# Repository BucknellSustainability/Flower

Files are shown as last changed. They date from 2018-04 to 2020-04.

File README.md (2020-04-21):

# Overview
Flower is a data collection and visualization system made for the Renewable Energy Scholars at Bucknell University. It is made of several components that require each other to function. The purpose of the project is to make research easier as well as publicize the sustainability efforts at Bucknell.

# How to use this project
There are `README.md`s in each of the main directories for how to use each component of the project. You will need a MySQL DB running (`/backend/sql`), run the Flask server (`/backend`), compile the React code and run the php server (`/web`), and put code on the Raspberry Pis (`/raspberrypi`), and load programs onto Arduinos (`/arduino`).  

# Running system at Bucknell
We suggest running this system with Bucknell linuxremote servers because that is what we developed on. Any other system is not guarenteed to work, but we will have instructions to give it a shot.

If attempting to run on Bucknell systems, we advise cloning the repo into a user's `~/public_html/` directory (create it if it doesn't exist) to enable the Bucknell Apache server to handle the web page serving.

The system needs to be run on linuxremote3 for the below part to function.

Now go into the script directory and run:
```
./restart_flask.sh
```
If any changes need to be done to the flask server, just run that script again to restart it

# API Keys and Deployment Specific Values
API Keys and other deployment specific values have been removed from the repo to ensure security and flexibility for different deployments.  You will NEED to complete steps 1-6 to have any component of the project to work.

1. Create a file called `config.json` in the repo's root directory.
2. Add this code:
```
{
  "DB_URL" : "",
  "DB_USERNAME" : "",
  "DB_PASSWORD" : "",
  "DB_NAME": ""
}
```
3. Fill out all values of the empty strings with information for your DB/API key info
4. Create a file called `deployment.json` in the repo's root directory.  There are all things unique to your deployment.
5. Add this code:
```
{
 "APPROVAL_LINK": "",
  "FLASK_SERVER": "",
  "GOOGLE_CLIENT_ID": "",
  "REDIRECT_URL": "" 
}
```
6. Fill out all values of the empty string with the information for your deployment
7. Access the values where needed:
    * Python:
       ```
       import json
       with open('path/to/config.json', 'r') as f:
           config = json.load(f)

       config['KEY_NAME']
       ```
    * PHP:
      ```
      $config = json_decode(file_get_contents("path/to/config.json"));
      printf("%s", $config->KEY_NAME);
      ```
    * JS:
      !!!This should only be used with the deployment.json so that DB credentials or other important information isn't leaked on the client side with `config.json`
      ```
      <script src="https://ajax.googleapis.com/ajax/libs/jquery/3.3.1/jquery.min.js"></script> 
      <script type="text/javascript" src="../common/load-deployment.js" ></script>
      ...
      deploy_config["KEY_NAME"]
      ```
`KEY_NAME` is the key string in your config file such as `DB_NAME` or `FLASK_SERVER`.

This `config.json` and `deployment.json` won't get committed because it is in the `.gitignore` so you will need to do this for each clone of the repo, but it should persist unless you delete the file.

## Linters

### Python - autopep8
To install autopep8 run
```
pip install autopep8
```
Install the `python-autopep8` package in Atom with either `apm install python-autopep8` or through the built in Atom package manager.

Then to run the linter in Atom, highlight all of the text you want to format and then press `Ctrl-shift-p` and type in `autopep8` and then press `Enter` to format the Python code.

You can also run it from the command line with `autopep8 [--in-place] [other-options] filename`.

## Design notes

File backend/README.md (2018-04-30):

# Setup on any system
Coming soon to a movie theatre near you

# Manual setting up backend on Bucknell's linuxremote
1. Make sure that you have a `config.json` and `deployment.json` file in the root directory of the repo. If you don't, read instructions in `/README.md`

2. Run the folowing commands to make sure you are using python 3.6
```
module load python/3.6
```

3. Run the following commands to install all necessary python packages
```
pip install --user --upgrade google-auth flask flask-mysql
```

4. Go to the `scripts` directory and run the flask starting script
```
./restart_flask.sh
```

# Using the api
Each of these end points need to be accessed by an http request to `https://eg.bucknell.edu/energyhill/{endpoint}` where `{endpoint}` which is described below.  Each http request needs to be accompanied with parameters described below.

Generally, hardcoding the URL shouldn't be in code, but instead you should use the deployment config setup (information found in `/README.md`)

## Reading from the DB
- `{endpoint}`: `read`
- allowed http requests: `GET`
- parameters:
    - `table`: the table which to pull data from. Must be a valid table in the DB.
    - `fields`: the column names which should be retrieved. Must be valid column of `table`
    - `condition_fields`: the condition field to compare a value equal to.  Must be a valid column name for `table` or `null` (if `null`, then values must also be `null`)
    - `condition_values`: the values that must match up with the `condition_fields` to make a condition. Each subsequent field/value pair will be `AND`ed with the others.
- form: `SELECT fields FROM table WHERE condition_fields[0] = condition_values[0] AND condition_fields[1] = condition_value[1] AND ...`
- returns: JSON serialization of DB output

## Inserting into the DB
- `{endpoint}`: `insert`
- allowed http requests: `POST`
- parameters:
    - `idtoken`: the token that Google Auth gives to the client
    - `table`: the table which to insert data into. Must be a valid table in DB.
    - `fields`: the column names which should be inserted into. Must be valid columns in `table`.
    - `values`: the values to place into the fields in the same order that the fields are in
- form: `INSERT INTO table (fields) VALUES (values)`
- returns: JSON serialization of DB output

## Update the DB
- `{endpoint}`: `update`
- allowed http requests: `POST`
- parameters:
    - `idtoken`: the token that Google Auth gives to the client
    - `table`: the table which to update data from. Must be valid table in DB.
    - `fields`: the columns of which to update information with. Must be valid columns in `table`
    - `values`: the values to update into the fields columns in the same order that the fields are in.
    - `condition_fields`: the condition field to compare a value equal to.  Must be a valid column name for `table` or `null` (if `null`, then values must also be `null`)
    - `condition_values`: the values that must match up with the `condition_fields` to make a condition. Each subsequent field/value pair will be `AND`ed with the others.
- form: `UPDATE table SET (fields[0] = values[0], fields[1] = values[1], ...) WHERE condition_fields[0] = condition_values[0] AND condition_fields[1] = condition_value[1] AND ...`
- returns: JSON serialization of DB output

## Delete from the DB
- `{endpoint}`: `delete`
- allowed http requests: `POST`
- parameters:
    - `idtoken`: the token that Google Auth gives to the client
    - `table`: the table which to delete data from. Must be valid table in DB.
    - `condition_fields`: the condition field to compare a value equal to.  Must be a valid column name for `table` or `null` (if `null`, then values must also be `null`)
    - `condition_values`: the values that must match up with the `condition_fields` to make a condition. Each subsequent field/value pair will be `AND`ed with the others.
- form: `DELETE FROM table WHERE condition_fields[0] = condition_values[0] AND condition_fields[1] = condition_value[1] AND ...`
- returns: JSON serialization of DB output

## Get the User Profile
- `{endpoint}`: `get-profile`
- allowed http requests: `POST`
- parameters:
    - `idtoken`: the token that Google Auth gives to the client
- returns: JSON serialization of all profile information for user log in

## Get all of the sensors with project information
- `{endpoint}`: `get-all-sensors`
- allowed http requests: `GET`
- parameters: None
- returns: JSON serialization of all sensors and their project information

## Ask admins for approval for user
- `{endpoint}`: `request-access`
- allowed http requests: `POST`
- parameters:
    - `idtoken`: the token that Google Auth gives to the client, needs to be for the user that wants access
- returns: nothing

## Approve user for dashboard access
- `{endpoint}`: `approve-user`
- allowed http requests: `POST`
- parameters:
    - `idtoken`: the token that Google Auth gives to the client, needs to be admin user
    - `userid`: the userid from the DB that is to be approved access
- returns: nothing

## Upload a file
- `{endpoint}`: `store-code`
- allowed http requests: `POST`
- parameters:
    - `idtoken`: the token that Google Auth gives to the client, needs to be admin user
    - `deviceid`: the deviceid from the DB that the code is to uploaded to
    - file: a `.hex` file to be uploaded (see `web/control-panel/codeupload.html` for an example)
- returns: nothing

## Download a file
- `{endpoint}`: `download-code`
- allowed http requests: `GET`
- parameters:
    - `uploadid`: the uploadid from the DB that specifies the code upload
- returns: the `.hex` file requested

## Log error message after attempt at code upload
- `{endpoint}`: `log-error`
- allowed http requests: `POST`
- parameters:
    - `deviceid`: the deviceid from the DB that the code upload was attempted on
    - `error_msg`: the full error message to be saved and relayed
- returns: nothing

## Log success message after attempt at code upload
- `{endpoint}`: `log-success`
- allowed http requests: `GET`
- parameters:
    - `deviceid`: the deviceid from the DB that the code upload was attempted on
- returns: nothing

## Check for status of code upload
- `{endpoint}`: `check-error`
- allowed http requests: `GET`
- parameters:
    - `deviceid`: the deviceid from the DB that is waiting to be attempted at code upload
- returns: the error message for the device if failure and `SUCCESS` if success

## Get the most recent reading for a sensor
- `{endpoint}`: `get-sensor-last-reading`
- allowed http requests: `GET`
- parameters:
    - `sensorid`: the id of the sensor that you want the most recent reading from
- returns: json with one key - `value` which corresponds to the data of the most recent reading

## Change the admin status of user
- `{endpoint}`: `set-admin-status`
- allowed http requests: `POST`
- parameters:
    - `idtoken`: the token that Google Auth gives to the client, needs to be admin user 
    - `userids`: the userids of the users to have their isAdmin status set to adminstatus
    - `adminstatus`: the status that is to be set for the users. Must be strictly either `0` or `1`
- returns: empty string on success, 503 status if user is denied access

## Get the project that the user doesn't own
- `{endpoint}`: `get-all-others-projects
- allowed http requests: `GET`
- parameters:
    - `userId`: the userid of the user whose projects should not be included
- returns: list of objects that contain projectId and name that aren't owned by user

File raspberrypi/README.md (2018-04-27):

# Setting up the Pi

## Installing the NOOBS OS

You can find the lastest download for the NOOBS OS here: https://www.raspberrypi.org/downloads/noobs/

No special setup is required for this project; any installation of NOOBS
will work.

## Installing Libraries

This project uses the `pymysql` and `pyserial` libraries. To install these
libraries for use with `python3`, we use the `pip3` manager. Run these commands:
```
sudo apt-get install pip3
sudo pip3 pymysql pyserial
```

If a library is missing, the scripts will output an error message with
installation instructions.

## Command line / gui mode

### Boot into Command Line
To get the pi to boot into the command line:

1) sudo raspi-config
2) Go to Boot Options > Desktop/CLI > Console Autologin

### Boot into GUI Mode
To return it to GUI mode:

1) sudo raspi-config
2) Go to Boot Options > Desktop/CLI > Desktop Autologin

If you would like to continue with GUI Mode, the commands must be run in a terminal window.

### Security
If autologin is ever disabled, the credentials are:
- username: `pi`
- password: ``		(empty)

The login is not secret, because we are not trying to secure the pi. If a malicious user has physical access to the pi with a screen, then we have already lost, since the server.py file is unprotected.

## Fixing the Keyboard

The default NOOBS installation comes with a United Kingdom keyboard configuration. This switches some keys (such as `"` and `@`) that are critical for this setup process and coding in general. You can fix it through the GUI settings menu, but that isn't permanent! To fix it permanently:
1) `sudo raspi-config`
2) Select the Keyboard Setup menu.
3) Select the first entry for keyboards (usually generic 101 or something similar).
4) Scroll down and select `Other` to get to the Country menu.
5) Select `United States`
6) Select `English (US)` (You may have to scroll up to see it.)
7) `reboot`

## Setting up the Internet

Follow the instructions provided in the template `wpa_supplicant.conf` file.

## Download the Repository

From the home directory, use git to download this repository:

`git clone https://github.com/BucknellSustainability/Flower.git`

## Create the `config.json` File

Creating this file is covered elsewhere in this repo. The pi server requires the DB-related keys inside the config.

## Setting the timezone

To set the timezone to EST:

1) `sudo dpkg-reconfigure tzdata`
2) Select `America`
3) Scroll down and select `New York`
4) `reboot`

## Start-On-Boot
To setup a cron job to restart the server every reboot:
1) `crontab -e`
	Note: If it asks you for an editor, choose vim or nano.
2) Add the line `@reboot cd ~/Flower/raspberrypi && python3 ~/Flower/raspberrypi/server.py`
3) `reboot`

### Viewing Server that was Started via Boot
To see the status of the server, do:
1) `ps -A | grep py`
2) Note the Process ID of server.py (a.k.a. the `PID`). The `server.py` process is the only python process.
3) `sudo /proc/<PID>/fd/1 | tail -f` where `<PID>` is the Process ID of`server.py`
	Note: Use 1 to see stdout, use 0 to see stderr
	Note: The output is buffered. It can take some time for the output to update.
	Note: Currently, it only uses stdout. Nothing is printed to stderr.

# Troubleshooting the Server

	Error: "Can't connect to MySQL server on..."
	Fix: 
		The Pi has read the `config.json` file, but cannot connect to
		the database. Check your internet connection. If the internet
		conneciton is correct, check the connection credentials in the
	   	`config.json` file.

	Error: "[Errono 2] could not open port /dev/tty<whatever>..."
	Fix: 
		The Pi knows an arduino is plugged in, but cannot read data from
		it. This can happen if the USB connection has some dust in it;
		try unplugging it and blowing it off. It can also happen if two
		copies of the server process are running. Run `ps -A | grep py`;
		there should only ever be one instance of `python3`. If there are
		more, type `kill -s TERM <PID>`, where `PID` is the number listed
		next to the python instance in the `ps` response. Generally, you
		will want to kill the instance with the lowest `pid`.	
	Error: The arduino definitely outputs stuff, but the pi doesn't see any output!
		Check the baud rate of the arduino. The server expects input at
		115200 baud. This corresponds to a `Serial.begin(115200)` line in
		the arduino `setup()` function. By default, arduinos use 9600 baud.
		Normally, when there is a baud rate mismatch, stuff looks like
		gibberish. However, when 9600 baud is sent to 115200 baud, it looks
		like nothing is sent. This is easily fixed by adding the
		`Serial.begin(115200)` line to your arduino program.
	
# Design

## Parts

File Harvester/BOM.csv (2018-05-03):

Module | Name | Description/Notes | Link | PN | Dimensions | Price Per | Quanitity per box | Quantity total | Price per Box | Price for all | Number of boxes | Extra box components
Pi | Raspberry Pi 3 Model B | Newark is the official distributor | http://www.newark.com/raspberry-pi/raspberrypi3-modb-1gb/sbc-raspberry-pi-3-mod-b-1gb-ram/dp/77Y6520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 |  | 4.8 x 2.99 x 1.34 inches | $35.00 | 1 | 1 | $35.00 | $35.00 | 1 | 0
Pi | micro usb breakout | Hardwire power to raspi | https://www.digikey.com/product-detail/en/sparkfun-electronics/BOB-10031/1568-1192-ND/5673778 | 1568-1192-ND |  | $3.95 | 1 | 1 | $3.95 | $3.95
Pi | SanDisk Ultra class 10 16GB | microSD Cards for Pis | http://a.co/50qHHlO |  |  | $9.90 | 1 | 1 | $9.90 | $9.90
Pi | USB Hub | comes with USB cable and screws | https://www.digikey.com/product-detail/en/tripp-lite/U223-004-IND/TL822-ND/4439408 | TL822-ND |  | $70.06 | 1 | 1 | $70.06 | $70.06
Pi | USB cable | A-B for arduinos, and pi panel mount. | https://www.digikey.com/product-detail/en/molex-llc/0887329002/WM17533-ND/1866799 | WM17533-ND |  | $2.11 | 5 | 5 | $10.55 | $10.55 |  | Per Box | Total
Pi | HDMI cable |  | https://www.digikey.com/product-detail/en/qualtek/1721001-03/Q396-ND/1531323 | Q396-ND |  | $7.78 | 1 | 1 | $7.78 | $7.78 | Pi | $137.24 | $137.24
 |  |  |  |  |  |  |  |  |  |  | Arduino | $232.13 | $232.13
Arduino | Arduino Mega 2560 Rev3 |  | https://www.digikey.com/product-detail/en/arduino/A000067/1050-1018-ND/2639006 | 1050-1018-ND | 4.4 x 2.4 x 0.8 inches | $38.50 | 4 | 4 | $154.00 | $154.00 | Box | $325.30 | $325.30
Arduino | Power cable | Must be used to power USB hub off 5V | https://www.digikey.com/product-detail/en/tensility-international-corp/10-01936/839-1250-ND/5638260 | 839-1250-ND |  | $2.83 | 1 | 1 | $2.83 | $2.83 | Box Con | $207.15 | $207.15
Arduino | Grove Mega Shield v1.2 | Grove shield for megas | https://www.digikey.com/product-detail/en/seeed-technology-co-ltd/103020027/1597-1153-ND/5774944 | 1597-1153-ND |  | $10.10 | 4 | 4 | $40.40 | $40.40 | Sensor Cables | $273.03 | $273.03
Arduino | 4-40 Washer | 4-40 (optional) |  |  |  | $0.0000 | bulk | 100 | $0.00 | $0.00 | Sensors | $200.08 | $200.08
Arduino | 4-40 Machine Screw | 4-40 3/4inch | https://www.digikey.com/product-detail/en/b-f-fastener-supply/PMSSS-440-0075-PH/H707-ND/274918 | H707-ND |  | $0.0912 | bulk | 100 | $9.12 | $9.12 | TOTAL | $1,374.93 | $1,374.93
Arduino | 4-40 Nut | 4-40 | https://www.digikey.com/product-detail/en/b-f-fastener-supply/HNSS440/H724-ND/274935 | H724-ND |  | $0.0486 | bulk | 100 | $4.86 | $4.86
Arduino | 4-40 PCB space | 1/4inch | https://www.digikey.com/product-detail/en/raf-electronic-hardware/1124-4-N/1772-1919-ND/7681330 | 1772-1919-ND |  | $0.2000 |  | 25 | $5.00 | $5.00
Arduino | Grove connectors | 5 pack, 50cm ea, cut to get 10x25cm wires |  | 1597-1088-ND |  | $3.98 | 4 | 4 | $15.92 | $15.92
Box | Enclosure | NBF-32032 - ABS indoor use. Plate is 18.23 x 14.25 |  | 377-1768-ND |  | $62.05 | 1 | 1 | $62.05 | $62.05
Box | Vent | with nut |  | 1754-1230-ND |  | $2.90 | 1 | 1 | $2.90 | $2.90
Box | 120VAC to 12V @ 60W | DIN mount, arduinos, misc loads, 40 mm width | https://www.digikey.com/product-detail/en/mean-well-usa-inc/MDR-60-12/1866-1042-ND/7705072 | 1866-1042-ND |  | $23.18 | 1 | 1 | $23.18 | $23.18
Box | 120VAC to 5V @ 50 W | DIN mount, raspi, usb hub, 40 mm width | https://www.digikey.com/product-detail/en/mean-well-usa-inc/MDR-60-5/1866-1045-ND/7705075 | 1866-1045-ND |  | $23.18 | 1 | 1 | $23.18 | $23.18
Box | QC terminals .25" | crimp 18-22 awg | https://www.digikey.com/product-detail/en/te-connectivity-amp-connectors/2-520184-2/A27817-ND/289250 | A27817-ND |  | $0.15 | bulk | 50 | $7.50 | $7.50
Box | Hookup wire, set | 22 awg | https://www.digikey.com/product-detail/en/adafruit-industries-llc/3111/1528-1744-ND/6198256 | 1528-1744-ND |  | $15.95 | 1 | 1 | $15.95 | $15.95
Box | Breaker | DIN 5A @ 120VAC, 13 mm width | https://www.digikey.com/product-detail/en/weidmuller/9926251005/281-2400-ND/1788797 | 281-2400-ND |  | $23.28 | 1 | 1 | $23.28 | $23.28
Box | Disconnect, 12V and 5V | Term block, screw, 6.2mm width | https://www.digikey.com/product-detail/en/phoenix-contact/3046139/277-3277-ND/2426275 | 277-3277-ND |  | $3.25 | 10 | 10 | $32.50 | $32.50
Box | Ground | Term block, screwn 5.2mm width | https://www.digikey.com/product-detail/en/phoenix-contact/3044092/277-2031-ND/2051194 | 277-2031-ND |  | $4.09 | 10 | 10 | $40.90 | $40.90
Box | DIN rail | 10" slotted cut from 1m | https://www.mcmaster.com/#din-rails/=1bzvlbl | 8961K15 |  | $5.27 | 1 | 1 | $5.27 | $5.27
Box | M5 washer |  | https://www.mcmaster.com/#91166A240 | 91166A240 |  | $0.0223 | bulk | 100 | $2.23 | $2.23
Box | M5 screw | M5x12, to attach din rail to mount plate | https://www.mcmaster.com/#92005A322 | 92005A322 |  | $0.0504 | bulk | 100 | $5.04 | $5.04
Box | M5 nut |  | https://www.mcmaster.com/#90591A260 | 90591A260 |  | $0.0269 | bulk | 100 | $2.69 | $2.69
Box | Acrylic panel | clear, 1/4", 24x36, each panel is 18.23 x 14.24, so get two panels out of one sheet | https://www.mcmaster.com/#8560K434 | 8560K434 |  | $78.63 | cut | 1 | $78.63 | $78.63
Box Con | USB plug |  |  | 708-1357-ND |  | $17.37 | 1 | 1 | $17.37 | $17.37
Box Con | USB plug cover |  |  | 708-1179-ND |  | $3.28 | 1 | 1 | $3.28 | $3.28
Box Con | HDMI plug |  | https://www.digikey.com/product-detail/en/switchcraft-inc/EHHDMI2B/SC2476-ND/4248670 | SC2476-ND |  | $12.76 | 1 | 1 | $12.76 | $12.76
Box Con | Power inlet C14 | 0.25" quick connect terminals | https://www.digikey.com/product-detail/en/schurter-inc/6100.3300/486-1003-ND/569903 | 486-1003-ND |  | $1.52 | 1 | 1 | $1.52 | $1.52
Box Con |  | M12 panel (MUST ORDER 50 for qt discount!) |  | 1195-4108-ND |  | $10.76 | 16 | 16 | $172.22 | $172.22
Sensor Cables |  | M12 cable 2m **get 10 for qt discount |  | 1195-6206-ND |  | $13.32 | 3 | 3 | $39.96 | $39.96
Sensor Cables |  | M12 cable 5m |  | 1195-6207-ND |  | $16.33 | 10 | 10 | $163.28 | $163.28
Sensor Cables |  | M12 cable 10m **get 10 for qt discount |  | 1195-6208-ND |  | $23.26 | 3 | 3 | $69.79 | $69.79
Sensors | Temperature and humidity sensor | Grove sensor board - mount in box | https://www.digikey.com/scripts/DkSearch/dksus.dll?Detail&itemSeq=255062838&uq=636567951937632056 | 1597-1124-ND |  | $6.02 | 4 | 4 | $24.08 | $24.08
Sensors | Temperature and humidity sensor | Grove sensor board - External | https://www.digikey.com/scripts/DkSearch/dksus.dll?Detail&itemSeq=255062838&uq=636567951937632056 | 1597-1124-ND |  | $6.02 | 4 | 4 | $24.08 | $24.08
Sensors | Liquid level sensor | Dwyer submersible probe, 4-20 mA output | https://www.dwyer-inst.com/products/product.cfm?Group_ID=616#ordering | SBLT2-3.5M-5M |  | $228.50 | 0 | 0 | $0.00 | $0.00
Sensors | Soil Humidity Sensor | Grove sensor board - External | https://www.digikey.com/product-detail/en/seeed-technology-co-ltd/101020008/1597-1141-ND/5482619 | 1597-1141-ND |  | $5.00 | 4 | 4 | $20.00 | $20.00
Sensors | Barometer | Grove sensor board - mount in box | https://www.digikey.com/product-detail/en/seeed-technology-co-ltd/101020192/1597-1386-ND/6131524 | 1597-1386-ND |  | $9.08 | 4 | 4 | $36.32 | $36.32
Sensors | RTD Probe | 10", M12 Mount probe - External | https://www.digikey.com/product-detail/en/adafruit-industries-llc/3290/1528-2090-ND/6560922 | 1528-2090-ND |  | $11.95 | 8 | 8 | $95.60 | $95.60
Sensors |  |  |  |  |  |  |  | 0 | $0.00 | 0
Sensors |  |  |  |  |  |  |  | 0 | $0.00 | 0
Sensors |  |  |  |  |  |  |  | 0 | $0.00 | 0
Sensors |  |  |  |  |  |  |  | 0 | $0.00 | 0
Sensors |  |  |  |  |  |  |  | 0 | $0.00 | 0
Sensors |  |  |  |  |  |  |  | 0 | $0.00 | 0
Sensors |  |  |  |  |  |  |  | 0 | $0.00 | 0
Sensors |  |  |  |  |  |  |  | 0 | $0.00 | 0
 |  |  |  |  |  |  |  |  |  | 0
 |  |  |  |  |  |  | Total |  | $1,374.93 | $1,374.93

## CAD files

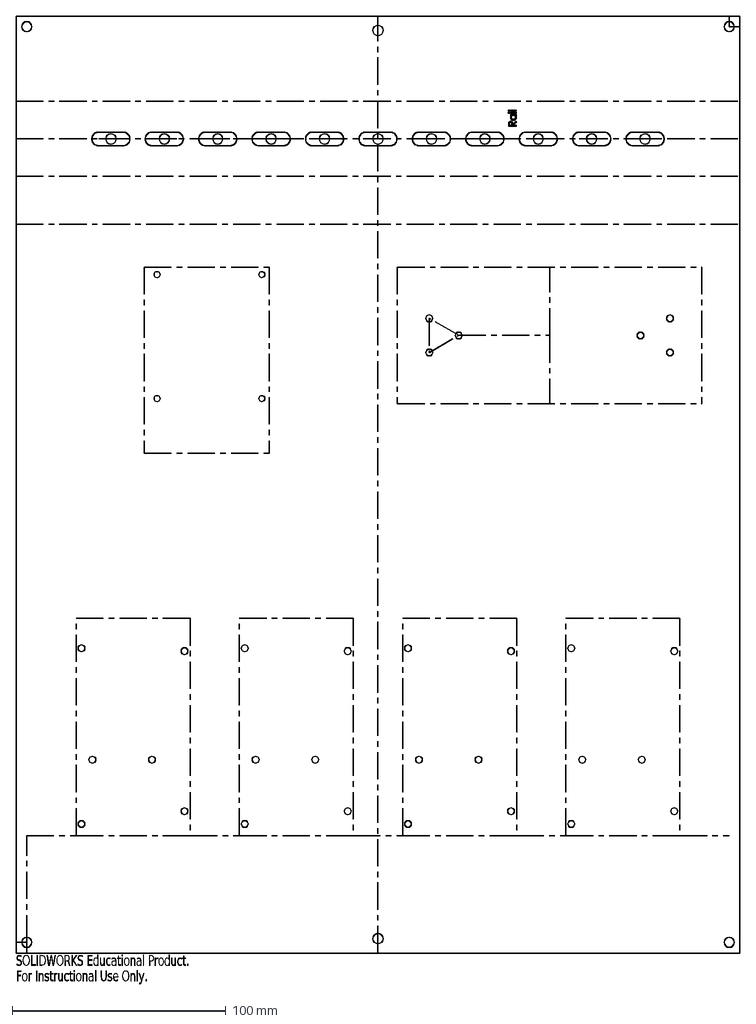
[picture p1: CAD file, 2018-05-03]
Harvester/backplane_wConstruction.DXF
SOLIDWORKS Educational Product.
For Instructional Use Only.

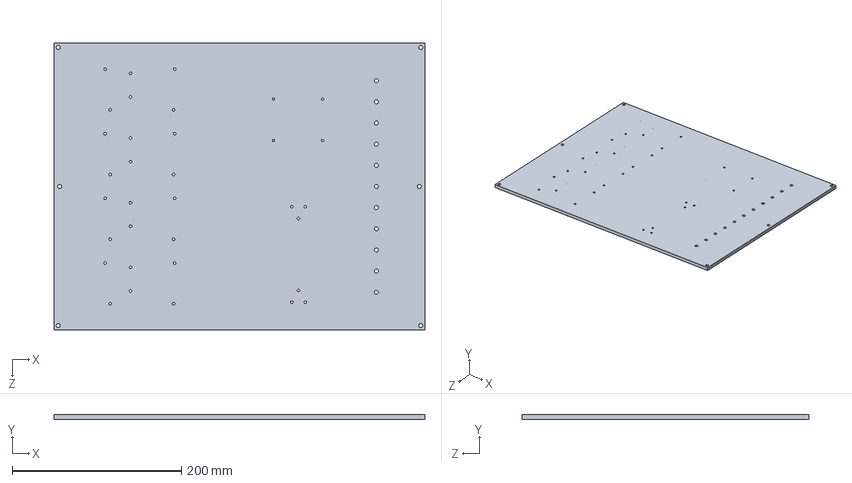
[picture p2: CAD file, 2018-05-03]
Harvester/backplane.SLDPRT
438.5 x 5.60 x 338.8 mm

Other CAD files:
Harvester/sensor_marker.SLDPRT
Harvester/backplane.DXF
Harvester/sensor_marker.DXF

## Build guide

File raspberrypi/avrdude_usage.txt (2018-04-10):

The magic incantation to send a file $FILE to a $BOARD using port $PORT is:

avrdude -c wiring -p $BOARD -P $PORT -b 115200 -D -Uflash:w:$FILE:i

Currently, we only support ATMega 2560's, which have $BOARD=m2560. You can also
use $BOARD=atmega2560; they're identical.

$PORT is the path to the tty entry in /dev/. For most arduinos, that is /dev/ttyUSB*;
for Megas, it's /dev/ttyACM*, where * is a number 0 or greater, chosen semi-arbitrarily
by the Linux kernel.

Note that $FILE must be an absolute path!

The baud rate (`-b 115200`) is optional (regardless of what baud the currently loaded script
is using); it defaults to 9600. I recommend using 115200, because that will make the file
transfer as fast as possible.

If everything goes well, the exit code will be 0.

To verify the board is the correct kind, the command is the same, except without the -D
and -U arguments:

avrdude -c wiring -p $BOARD -P $PORT

IMPORTANT NOTE: For some STUPID reason, avrdude sends 100% of its output to stderr, NOT
stdout.

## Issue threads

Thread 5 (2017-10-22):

Email ECST about creating site

BenMatase, 2017-10-22:
We were told that ECST is in charge of the Wordpress pages that Bucknell already have.

BenMatase, 2017-10-22:
After emailing them, they said

> You can create a Wordpress site by going to http://blogs.bucknell.edu. There is also another Wordpress network called scholar.bucknell.edu. As far as I know the primary difference is simply the site address, but if you're interested in that and want to know more, I can put you in touch with the Digital Pedagogy & Scholarship group in L&IT.

On Thu, Oct 19, 2017 at 12:37 AM, Benjamin Matase <bdm015@bucknell.edu> wrote:
Hello,

We are a Computer Science Senior Design group trying to create a unified site to host a showcase for the sustainability efforts on campus (specifically Energy Hill). Our senior design project needs a Wordpress site and we think it would be best to have it hosted on Bucknell servers, whether it be a subsite of an existing Wordpress site or a new site.  This site would be for BCSE/RES, specifically Nate Siegel, and we were told that you are the people to contact.  What are your thoughts?

Thanks,
Benjamin Matase

BenMatase, 2017-10-24:
Determined that were going to create the wordpress site on the blogs.bucknell.edu and then see if that is too restricting.  Will reopen if find that we need to look at more options

Closed 2017-10-24.

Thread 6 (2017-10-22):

Get Hardware to develop on

BenMatase, 2017-10-22:
Marchiori said that he can provide one Arduino and one Raspberry Pi for us to use.  We should also look into ordering one and some sensors for the client to use permanently

BenMatase, 2017-10-23:
This should be relatively easy to get one of each

Closed 2017-10-28.

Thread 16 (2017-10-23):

Create landing page

BenMatase, 2017-10-23:
We want a single landing page that leads to all sites for sustainable efforts on campus.  Originally, we were thinking of a site with a map of Bucknell's campus with map markers on all of the different projects.  You can click on them to go to the corresponding sites to learn more.

BenMatase, 2017-11-09:
Although we haven't beautified the page yet, I'm going to close since we are most of the way there

Closed 2017-11-09.

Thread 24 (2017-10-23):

Create tutorial to connect Arduino to system

BenMatase, 2017-10-23:
This should be pretty easy to use and self-explanatory.  Having students with a non-technical background should be tested on

BenMatase, 2017-10-23:
This can't really be worked on until we get a system together.  This could be converted to an epic later

DTV96Calibre, 2018-03-04:
This has been partially resolved. A tutorial for connecting the arduino to a pi node and claiming the arduino through the web dashboard needs to be written.

BenMatase, 2018-03-28:
Now that Dan has updated information, I believe this Arduino part is complete

Closed 2018-03-28.

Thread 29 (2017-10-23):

Determine information necessary for landing page

BenMatase, 2017-10-23:
I'm thinking that a map with points and a little blurb could be nice, but other information could be useful as well.

BenMatase, 2017-10-23:
We have a sketch of what we think the landing page should look like somewhere...

BenMatase, 2017-11-04:
I think that having the title of "Bucknell Sustainability" with the nice big map and a list of places below for the people that don't want to use the map should be good.

Closed 2017-11-04.

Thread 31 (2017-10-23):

Create library for Arduino to connect to Raspberry Pi

BenMatase, 2017-10-23:

BenMatase, 2017-10-23:
This could probably be made into an Epic since there is a lot that goes into it

BenMatase, 2017-11-13:
Make a consolidated library for Pi set up

BenMatase, 2018-01-22:
Matt is working on this to refactor current Arduino code to be like a "library" but will really just be a file to add

BenMatase, 2018-01-23:
@Phlosioneer If you want to break this up into an epic, feel free. I just don't know what the different parts will be

BenMatase, 2018-02-12:
Completed by #246

Closed 2018-02-12.

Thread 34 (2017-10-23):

Create program to receive data from Raspberry Pi on server

BenMatase, 2017-10-23:

BenMatase, 2017-10-23:
This will require determining the interface of getting data from Pi to server program

BenMatase, 2017-11-13:
It seems that we have done this by inserting into the DB directly

Closed 2017-11-13.

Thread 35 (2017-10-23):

Get permission to run program on Bucknell server

BenMatase, 2017-10-23:

BenMatase, 2017-10-23:
Difficulty depends on how hard it is to get program to run.  Could always use linux remote...

BenMatase, 2017-11-13:
Got our own linux user account, duplicate of another issue

Closed 2017-11-13.

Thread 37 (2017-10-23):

Create way for Raspberry Pi to validate insertion into DB

BenMatase, 2017-10-23:

BenMatase, 2017-10-23:
Creating a storing mechanism that keeps data on Pi until the data is confirmed to be in DB.  On insertion, server program could send message back to Pi

Phlosioneer, 2018-03-02:
This was solved a while ago.

Closed 2018-03-02.

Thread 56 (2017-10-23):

Create theme and corresponding CSS

BenMatase, 2017-10-23:

BenMatase, 2017-10-27:
/*
	Theme Name: Going Green Pro Theme
	Theme URI: http://my.studiopress.com/themes/goinggreen/
	Description: A mobile responsive and HTML5 theme built for the Genesis Framework.
	Author: StudioPress
	Author URI: http://www.studiopress.com/
	Version: 3.1

	Tags: brown, green, one-column, two-columns, responsive-layout, custom-menu, full-width-template, sticky-post, theme-options, threaded-comments, translation-ready, premise-landing-page

	Template: genesis
	Template Version: 2.1

	License: GPL-2.0+
	License URI: http://www.opensource.org/licenses/gpl-license.php
*/

/* Table of Contents

	- HTML5 Reset
		- Baseline Normalize
		- Box Sizing
		- Float Clearing
	- Defaults
		- Typographical Elements
		- Headings
		- Objects
		- Galleries
		- Forms
		- Tables
	- Structure and Layout
		- Site Containers
		- Column Widths and Positions
		- Column Classes
	- Common Classes
		- WordPress
		- Genesis
		- Titles
	- Widgets
		- Featured Content
	- Plugins
		- Genesis eNews Extended
		- Genesis Latest Tweets
		- Gravity Forms
		- Jetpack
	- Site Header
		- Title Area
		- Widget Area
	- Site Navigation
		- Header Navigation
		- Primary Navigation
		- Secondary Navigation
		- Responsive Menu
	- Content Area
		- Entries
		- After Entry
		- Pagination
		- Comments
	- Sidebars
	- Footer Widgets
	- Site Footer
	- Theme Colors
		- Going Green Pro Forest
		- Going Green Pro Mint
		- Going Green Pro Olive
	- Media Queries
		- max-width: 1268px
		- max-width: 1023px
		- max-width: 834px

*/

/*
HTML5 Reset
---------------------------------------------------------------------------------------------------- */

/* Baseline Reset (normalize.css 2.1.2)
	normalize.css v2.1.2 | MIT License | git.io/normalize
--------------------------------------------- */

article,aside,details,figcaption,figure,footer,header,hgroup,main,nav,section,summary{display:block}audio,canvas,video{display:inline-block}audio:not([controls]){display:none;height:0}[hidden]{display:none}html{font-family:sans-serif;-ms-text-size-adjust:100%;-webkit-text-size-adjust:100%}body{margin:0}a:focus{outline:thin dotted}a:active,a:hover{outline:0}h1{font-size:2em;margin:.67em 0}abbr[title]{border-bottom:1px dotted}b,strong{font-weight:bold}dfn{font-style:italic}hr{-moz-box-sizing:content-box;box-sizing:content-box;height:0}mark{background:#ff0;color:#000}code,kbd,pre,samp{font-family:monospace,serif;font-size:1em}pre{white-space:pre-wrap}q{quotes:"\201C" "\201D" "\2018" "\2019"}small{font-size:80%}sub,sup{font-size:75%;line-height:0;position:relative;vertical-align:baseline}sup{top:-0.5em}sub{bottom:-0.25em}img{border:0}svg:not(:root){overflow:hidden}figure{margin:0}fieldset{border:1px solid silver;margin:0 2px;padding:.35em .625em .75em}legend{border:0;padding:0}button,input,select,textarea{font-family:inherit;font-size:100%;margin:0}button,input{line-height:normal}button,select{text-transform:none}button,html input[type="button"],input[type="reset"],input[type="submit"]{-webkit-appearance:button;cursor:pointer}button[disabled],html input[disabled]{cursor:default}input[type="checkbox"],input[type="radio"]{box-sizing:border-box;padding:0}input[type="search"]{-webkit-appearance:textfield;-moz-box-sizing:content-box;-webkit-box-sizing:content-box;box-sizing:content-box}input[type="search"]::-webkit-search-cancel-button,input[type="search"]::-webkit-search-decoration{-webkit-appearance:none}button::-moz-focus-inner,input::-moz-focus-inner{border:0;padding:0}textarea{overflow:auto;vertical-align:top}table{border-collapse:collapse;border-spacing:0}

/* Box Sizing
--------------------------------------------- */

*,
input[type="search"] {
	-webkit-box-sizing: border-box;
	-moz-box-sizing:    border-box;
	box-sizing:         border-box;
}

/* Float Clearing
--------------------------------------------- */

.author-box:before,
.clearfix:before,
.entry-content:before,
.entry:before,
.footer-widgets:before,
.nav-primary:before,
.nav-secondary:before,
.pagination:before,
.site-container:before,
.site-footer:before,
.site-header:before,
.site-inner:before,
.widget:before,
.wrap:before {
	content: " ";
	display: table;
}

.author-box:after,
.clearfix:after,
.entry-content:after,
.entry:after,
.footer-widgets:after,
.nav-primary:after,
.nav-secondary:after,
.pagination:after,
.site-container:after,
.site-footer:after,
.site-header:after,
.site-inner:after,
.widget:after,
.wrap:after {
	clear: both;
	content: " ";
	display: table;
}

```/*
Defaults
---------------------------------------------------------------------------------------------------- */

/* Typographical Elements
--------------------------------------------- */

body {
	background: #e1dfd4 url(images/pattern-light.png);
	color: #7a7768;
	font-family: 'Lato', sans-serif;
	font-size: 16px;
	font-weight: 300;
	line-height: 1.625;
}

a,
button,
input:focus,
input[type="button"],
input[type="reset"],
input[type="submit"],
textarea:focus,
.button {
	-webkit-transition: all 0.1s ease-in-out;
	-moz-transition:    all 0.1s ease-in-out;
	-ms-transition:     all 0.1s ease-in-out;
	-o-transition:      all 0.1s ease-in-out;
	transition:         all 0.1s ease-in-out;
}

::-moz-selection {
	background-color: #3e3827;
	color: #fff;
}

::selection {
	background-color: #3e3827;
	color: #fff;
}

a {
	color: #319a54;
	text-decoration: none;
}

a img {
	margin-bottom: -4px;
}

a:hover {
	color: #984a23;
}

p {
	margin: 0 0 24px;
	padding: 0;
}

strong {
	font-weight: 700;
}

ol,
ul {
	margin: 0;
	padding: 0;
}

blockquote,
blockquote::before {
	color: #c3bbad;
}

blockquote {
	margin: 40px 40px 24px;
}

blockquote::before {
	content: "\201C";
	display: block;
	font-size: 30px;
	height: 0;
	left: -20px;
	position: relative;
	top: -10px;
}

.entry-content code {
	background-color: #333;
	color: #ddd;
}

cite {
	font-style: normal;
}

/* Headings
--------------------------------------------- */

h1,
h2,
h3,
h4,
h5,
h6 {
	font-family: 'Lato', sans-serif;
	font-weight: 300;
	line-height: 1.2;
	margin: 0 0 16px;
	padding: 0;
}

h1 {
	font-size: 36px;
}

h2 {
	font-size: 30px;
}

h3 {
	font-size: 24px;
}

h4 {
	font-size: 20px;
}

h5 {
	font-size: 18px;
}

h6 {
	font-size: 16px;
}

/* Objects
--------------------------------------------- */

embed,
iframe,
img,
object,
video,
.wp-caption {
	max-width: 100%;
}

img {
	height: auto;
}

.featured-content img,
.gallery img {
	width: auto; /* IE8 */
}

/* Gallery
--------------------------------------------- */

.gallery {
	overflow: hidden;
	margin-bottom: 28px;
}

.gallery-item {
	float: left;
	margin: 0;
	padding: 0 4px;
	text-align: center;
	width: 100%;
}

.gallery-columns-2 .gallery-item {
	width: 50%;
}

.gallery-columns-3 .gallery-item {
	width: 33%;
}

.gallery-columns-4 .gallery-item {
	width: 25%;
}

.gallery-columns-5 .gallery-item {
	width: 20%;
}

.gallery-columns-6 .gallery-item {
	width: 16.6666%;
}

.gallery-columns-7 .gallery-item {
	width: 14.2857%;
}

.gallery-columns-8 .gallery-item {
	width: 12.5%;
}

.gallery-columns-9 .gallery-item {
	width: 11.1111%;
}

.gallery-columns-2 .gallery-item:nth-child(2n+1),
.gallery-columns-3 .gallery-item:nth-child(3n+1),
.gallery-columns-4 .gallery-item:nth-child(4n+1),
.gallery-columns-5 .gallery-item:nth-child(5n+1),
.gallery-columns-6 .gallery-item:nth-child(6n+1),
.gallery-columns-7 .gallery-item:nth-child(7n+1),
.gallery-columns-8 .gallery-item:nth-child(8n+1),
.gallery-columns-9 .gallery-item:nth-child(9n+1) {
	clear: left;
}

.gallery .gallery-item img {
	border: none;
	height: auto;
	margin: 0;
}

/* Forms
--------------------------------------------- */

input,
select,
textarea {
	background-color: #fff;
	border: 1px solid #dddad3;
	border-radius: 3px;
	box-shadow: 1px 1px 3px #f8f8f8 inset;
	color: #c3bbad;
	font-family: 'Lato', sans-serif;
	font-size: 14px;
	font-weight: 300;
	padding: 16px;
	width: 100%;
}

input[type="checkbox"],
input[type="image"],
input[type="radio"] {
	width: auto;
}

input:focus,
textarea:focus {
	border: 1px solid #999;
	outline: none;
}

::-moz-placeholder {
	color: #c3bbad;
	opacity: 1;
}

::-webkit-input-placeholder {
	color: #c3bbad;
}

button,
input[type="button"],
input[type="reset"],
input[type="submit"],
.button,
.entry-content .button {
	background-color: #984a23;
	border: none;
	box-shadow: none;
	color: #fff;
	cursor: pointer;
	letter-spacing: 1px;
	padding: 16px 24px;
	text-transform: uppercase;
	width: auto;
}

button:hover,
input:hover[type="button"],
input:hover[type="reset"],
input:hover[type="submit"],
.button:hover,
.entry-content .button:hover {
	background-color: #319a54;
	color: #fff;
}

.entry-content .button:hover {
	color: #fff;
}

.button {
	border-radius: 3px;
	display: inline-block;
}

input[type="search"]::-webkit-search-cancel-button,
input[type="search"]::-webkit-search-results-button {
	display: none;
}

/* Tables
--------------------------------------------- */

table {
	border-collapse: collapse;
	border-spacing: 0;
	line-height: 2;
	margin-bottom: 40px;
	width: 100%;
}

tbody {
	border-bottom: 1px solid #ddd;
}

th,
td {
	text-align: left;
}

th {
	font-weight: bold;
	text-transform: uppercase;
}

td {
	border-top: 1px solid #ddd;
	padding: 6px 0;
}

/*
Structure and Layout
---------------------------------------------------------------------------------------------------- */

/* Site Containers
--------------------------------------------- */

.wrap {
	margin: 0 auto;
	max-width: 1140px;
}

.site-inner {
	background: rgba( 0, 0, 0, 0.3 );
	clear: both;
	margin: -160px auto 0;
	max-width: 1140px;
	padding: 10px;
	position: relative;
	z-index: 9;
}

.site-inner .wrap {
	background: #f5f4f2 url(images/pattern-light.png);
	background-size: 10px 10px;
	width: 100%;
}

.going-green-pro-landing .site-inner {
	margin: 60px auto;
	max-width: 960px;
}

/* Column Widths and Positions
--------------------------------------------- */

/* Content */

.content {
	background: #fff url(images/pattern-light.png);
	background-size: 10px 10px;
	float: right;
	padding: 0;
	width: 760px;
}

.content-sidebar .content {
	float: left;
}

.full-width-content .content {
	width: 100%;
}

/* Primary Sidebar */

.sidebar-primary {
	float: right;
	width: 360px;
	word-wrap: break-word;
}

.sidebar-content .sidebar-primary,
.sidebar-sidebar-content .sidebar-primary {
	float: left;
}

/* Column Classes
	Link: http://twitter.github.io/bootstrap/assets/css/bootstrap-responsive.css
--------------------------------------------- */

.five-sixths,
.four-sixths,
.one-fourth,
.one-half,
.one-sixth,
.one-third,
.three-fourths,
.three-sixths,
.two-fourths,
.two-sixths,
.two-thirds {
	float: left;
	margin-left: 2.564102564102564%;
}

.one-half,
.three-sixths,
.two-fourths {
	width: 48.717948717948715%;
}

.one-third,
.two-sixths {
	width: 31.623931623931625%;
}

.four-sixths,
.two-thirds {
	width: 65.81196581196582%;
}

.one-fourth {
	width: 23.076923076923077%;
}

.three-fourths {
	width: 74.35897435897436%;
}

.one-sixth {
	width: 14.52991452991453%;
}

.five-sixths {
	width: 82.90598290598291%;
}

.first {
	clear: both;
	margin-left: 0;
}

/*
Common Classes
---------------------------------------------------------------------------------------------------- */

/* WordPress
--------------------------------------------- */

.avatar {
	border-radius: 50%;
	float: left;

}

.alignleft .avatar {
	margin-right: 24px;
}

.alignright .avatar {
	margin-left: 24px;
}

.search-form {
	overflow: hidden;
}

.search-form input[type="search"] {
	color: #c3bbad;
	font-size: 12px;
	text-transform: uppercase;
}

.genesis-nav-menu .search input[type="submit"],
.widget_search input[type="submit"] {
	border: 0;
	clip: rect(0, 0, 0, 0);
	height: 1px;
	margin: -1px;
	padding: 0;
	position: absolute;
	width: 1px;
}

a.aligncenter img {
	display: block;
	margin: 0 auto;
}

img.centered,
.aligncenter {
	display: block;
	margin: 0 auto 24px;
}

a.alignnone {
	display: inline-block;
}
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

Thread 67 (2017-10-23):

Determine all use cases and see if tuple of doubles is enough

BenMatase, 2017-10-23:

BenMatase, 2017-10-23:
I think a tuple of doubles with some description and units could be all encompassing.

BenMatase, 2018-03-19:
This issue is irrelevant because we have switch to a JSON format to send data from Arduino

Closed 2018-03-19.

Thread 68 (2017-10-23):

Create parser for Pis to convert to format

BenMatase, 2017-10-23:

BenMatase, 2017-10-23:
Info from Arduinos should be pretty much formatted and ready to ship.  Programmer of Arduino should have to worry about descriptions and units and putting the data where it needs to go.  Raspberry Pi shouldn't need to be reprogrammed.

BenMatase, 2017-11-13:
Unnecessary because double format will work well

Closed 2017-11-13.

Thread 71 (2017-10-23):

Set up standard format for data

BenMatase, 2017-10-23:

BenMatase, 2018-03-19:
The data format issues have been resolved. We chose JSON to send from the Arduino to the Pi

Closed 2018-03-19.

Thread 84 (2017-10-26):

Get the Arduino to Read Numbers from Thermister

BenMatase, 2017-10-26:

BenMatase, 2017-10-27:
Code Marchiori gave us

```
#include <math.h>
#include <Xbee.h>

// Schematic:
// [Ground] ---- [10k-Resistor] -------|------- [Thermistor] ---- [+3.3V]
//                                 Analog 0

double Thermistor(int RawADC) {
  // Using Steinhart-Hart Thermistor equation
  float Temp;
  float v_out;

  v_out = (RawADC / 1024.0) * 3.3;
  Temp = 10000.0 * ( (3.3 / v_out) - 1);
  //Temp = log(10000.0*((1024.0/RawADC-1))); // Gets resistance of thermistor
  Serial.print("Resistance: ");
  Serial.print(Temp);

  //Temp = 1/(0.001129148 + (0.000234125 + (0.0000000876741 * Temp * Temp))*Temp);
  Temp = 1 / (0.001129148 + (0.000234125 * log(Temp)) + (0.0000000876741 * pow(log(Temp), 3)));
  Serial.print(", Kelvin: ");
  Serial.print(Temp);

  Temp = Temp - 273.15; // Convert K to C
  Serial.print(", Celsius: ");
  Serial.print(Temp);

  Temp = (Temp * 9.0)/ 5.0 + 32.0; // Convert C to F
  Serial.print(", Fahrenheit: ");
  Serial.print(Temp);

  return Temp;
}

void setup() {
  Serial.begin(115200);
}

void loop() {
  Serial.println(int(Thermistor(analogRead(0)))); // displays F
  delay(1000);
}
```

BenMatase, 2017-11-03:
Isn't this task done.  My understanding is that we can get the data to the Raspberry Pi so we need to just get the data from the Raspberry Pi to the DB. Right?

BenMatase, 2017-11-03:
I think you are currently working on #21

Phlosioneer, 2017-11-04:
Yes, this is done.

Closed 2017-11-04.

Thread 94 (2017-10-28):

Research Data Visualization JS Libraries

BenMatase, 2017-10-28:
Look at some different options and decide on one.  We talked about using Chart.js, but want to keep options open.  Maybe write up a small blurb about how to use it and some example code would be amazing.

BenMatase, 2017-10-28:
I know you are at a conference, but if you have any free time, it would be awesome if you could do some research on this since you are the JS expert on the team.

DTV96Calibre, 2017-10-28:
I found a library that can help us with developing an interactive map for accessing project pages.
[Polymaps](http://polymaps.org/)

DTV96Calibre, 2017-10-28:
Dygraph and Chart.js are both good candidates. Dygraph supports zoom and pan without a plugin but Chart.js is prettier.

BenMatase, 2017-11-01:
Marchiori's project that has similar use case to ours: http://www.eg.bucknell.edu/eswapp/index.html

DTV96Calibre, 2017-11-01:
They're using Highcharts for their graphing. I looked into it just now and it's really really good. It'll be free for us to use so I'll be looking into getting a helloworld going.

BenMatase, 2017-11-06:
I feel like research is done, I'm going to make a new task that is making first iteration

Closed 2017-11-06.

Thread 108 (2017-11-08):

Create Energy Hill accounts

BenMatase, 2017-11-08:
Need energyhill@bucknell.edu email and github account so that future development can be passed on easily or given to Nate/Marchiori

BenMatase, 2018-03-19:
We now have a "courtesy" account called energyhill from the Bucknell system. It has an email and wifi access. To my knowledge, it doesn't yet have the ability to create Google API stuff, which would be convenient. This sub-issue is detailed in #325

Closed 2018-03-19.

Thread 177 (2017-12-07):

Create helper SQL scripts

BenMatase, 2017-12-07:
This could include all the different queries that we use to fix the DB like the retroactive aggregation query.  I have this one saved locally in the bottom of this sql file:

This is a mess, but the idea is there.
```
# retroactively aggregate data
INSERT INTO datahourly
	(sensorId, averageValue, sampleRate, dateTime)
SELECT sensorId, AVG(value) as averageValue, 1 as sampleRate, FROM_UNIXTIME(FLOOR(UNIX_TIMESTAMP(dateTime) DIV 600) * 600) as t
  FROM data
  GROUP BY t
```

Closed 2018-01-23.

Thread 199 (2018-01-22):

Set up DB for 2 sensors

BenMatase, 2018-01-22:

BenMatase, 2018-01-29:
Need a Device (Arduino) table to uniquely identify each device

BenMatase, 2018-02-11:
This has been complete for a bit

Closed 2018-02-11.

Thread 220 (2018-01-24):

Figure out unique identifier for sensors/arduinos

BenMatase, 2018-01-24:

BenMatase, 2018-02-12:
This has been solved as we are going to use a hardware id tied to the board

Closed 2018-02-12.

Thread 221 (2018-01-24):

Adjust arduino/pi code to handle n sensors

BenMatase, 2018-01-24:

BenMatase, 2018-02-12:
This is still in progress.  Matt has the code ready, but he needs to test it and make sure it is working as intended

Closed 2018-02-23.

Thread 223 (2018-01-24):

Tiny JSON C api

Phlosioneer, 2018-01-24:
Arduino is just a fancy form of C, so we can make the library in C and copy it over. We need a C program that has:

- [x] `int start_packet()` - Sets up a global structure to start making a JSON response.
- [x] `int add_int_field(const char* name, int value)` - Adds a number to the JSON response.
- [x] `int add_double_field(const char* name, double value, int decimal_places)` - Adds a number to the JSON response.
- [x] `int add_text_field(const char* name, const char* value)` - Adds a string to the JSON response.
- [x] `int end_packet()` - Sends the packet along the Serial connection.

For now, we'll just use printf to print out the packet, until we actually use an Arduino.

To test these, make a C program that prompts a user to input (1) an int, (2) a double, (3) a text field, or (4) finish the packet and print it out.

BenMatase, 2018-01-26:
Please add an estimate to this

DTV96Calibre, 2018-02-01:
This is now implemented in code and works.

BenMatase, 2018-02-01:
Sweet. Throw up a PR

Closed 2018-02-07.

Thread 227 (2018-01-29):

Make Pi code robust

Phlosioneer, 2018-01-29:
- [ ] Handle arduinos being plugged in during operation
- [ ] Handle arduinos being unplugged
- [ ] Retain memory of arduinos being unplugged and then plugged back in
-- [ ] Even when plugged back into a different port
-- [ ] Even when the Pi is rebooted
- [ ] Handle power loss
-- [ ] Server starts when the pi boots
- [ ] Handle when arduinos draw too much power
- [ ] Handle network failure
- [ ] Handle arduino crashing

BenMatase, 2018-03-19:
Is this still in progress?

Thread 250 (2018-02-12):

Sprint 4

BenMatase, 2018-02-12:
- Adding/Removing sensors, devices, projects
- Arduino setup process for users
- code upload
- Admin privilages
- Adding/Removing RTT
- Alert System dashboard component

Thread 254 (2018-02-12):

Decide on how code upload is to be implemented

BenMatase, 2018-02-12:
We talked about a web interface to start, but need to talk more about further more complex interfaces.

DTV96Calibre, 2018-02-14:
The current plan of action is to implement an upload feature in the project dashboard allowing users to upload precompiled hex files which are then deployed to a specified Arduino.

BenMatase, 2018-02-14:
Sounds good. In future, we will look into an Arduino IDE plugin and in-browser code modifier.  For now we are keeping it simple

BenMatase, 2018-02-15:
The flow will be: IDE compiles source into hex file which can be exported using the IDE, the user will need to upload the hex file on our dashboard, this will send the file to the server and an entry will be created in the DB to point to that hex file, the backend will add a row in a "code upload alert" table that Pis will be getting back if they are connected to the Arduino that needs to be code uploaded, the Pi will check to see if it needs to grab the file every time it inserts data (often/~1s), the hex file will be transferred to the Pi through a DB query, then uploaded to the correct Arduino through the command line upload interface

Closed 2018-02-14.

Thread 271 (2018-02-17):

Add admin level protection to admin operations on DB

BenMatase, 2018-02-17:

BenMatase, 2018-03-19:
We've discussed this and we've put a lot of trust to the regular users since they are responsible. We are only restricting admin privileges to the adding/removal of users/admins

BenMatase, 2018-03-19:
Currently, any approved user can change any row in the database.  So admins are pointless as any user can escalate themselves to admin status. This could just be a small failsafe

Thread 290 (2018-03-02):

Reset Arduinos on startup

Phlosioneer, 2018-03-02:
The arduinos don't work after the pi reboots because they're drawing more power than the Pi can provide during bootup. Resetting the USB port should fix that.

BenMatase, 2018-03-19:
Having a powered usb hub should solve this issue

BenMatase, 2018-04-23:
Problem solved in Harvester since power is supplied in another way. The hub isn't necessary

Closed 2018-04-23.

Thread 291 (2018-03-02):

Add project name to arduino API

Phlosioneer, 2018-03-02:
Arduinos should include the key "project name" in every JSON response. The value of that key will be used by the pi to verify the arduino is correctly assigned to a project.

This is useful when a researcher exchanges arduinos with another project. The ID won't change, but the code running on the arduino will, and this method will catch that case.

The arduino API should have a way to set this value once - as part of setup / bootup (like setting the baud rate) - and then it'll be automatically appended to every JSON object that is sent.

Closed 2018-03-27.

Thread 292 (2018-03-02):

Make the Pi verify the project name matches

Phlosioneer, 2018-03-02:
Add code that checks the arduino's project name against the project that owns the arduino's hardware ID. If there's a mismatch, two projects have swapped arduinos, and a new device entry should be made in the DB. The old device entry will have its hardwareId set to `NULL`.

TODO: There should be some way to merge current devices and old, NULLed devices. This would be useful when a researcher swaps one arduino board for another; currently, they count as totally separate devices.

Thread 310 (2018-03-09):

Remove hard coding of Flask endpoint

BenMatase, 2018-03-09:
Should use the deployment.json file in the root directory

BenMatase, 2018-03-26:
We've made some progress in the React part, Tom is currently working on getting the JS parts to read from `deployment.json` instead of hardcoding because of timing/asynchronous issues

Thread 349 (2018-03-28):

Add button to let failed to log in user to request access to dashboard

BenMatase, 2018-03-28:

Closed 2018-04-03.

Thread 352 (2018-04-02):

Dashboard crashes if project doesn't have any devices

BenMatase, 2018-04-02:
get-all-sensors endpoint is causing this issue

BenMatase, 2018-04-24:
This was fixed by returning an empty list, but the correct user info

Closed 2018-04-24.

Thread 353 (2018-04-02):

Make sensors with no device under "null' project for get-all-sensors endpoint

BenMatase, 2018-04-02:
For get-all-sensors endpoint, any sensors that have no deviceId, put them under a seperate project for visualization sake.  This is to comply with our plans of deleting a device

BenMatase, 2018-04-25:
This has been changed to put them under the project with projectId = -1

Closed 2018-04-25.

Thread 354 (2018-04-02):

Visualizations are not showing all sensors, only showing last

BenMatase, 2018-04-02:

BenMatase, 2018-04-24:
Fixed this, was an issue with not having local variables and looping through and replacing a global variable

Closed 2018-04-24.

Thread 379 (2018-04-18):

Fix get-profile and get-all-sensors when missing link

BenMatase, 2018-04-18:
For instance, when there is a missing device or a project, the entire endpoint crashes because it tries to make a DB call that looks like
```
2018-04-17 20:12:36,381 - api - ERROR - Couldn't execute query - b'SELECT * FROM project WHERE projectId IN ()'
Traceback (most recent call last):
  File "/nfs/unixspace/linux/accounts/courtesy/e/energyhill/public_html/Flower/backend/db.py", line 61, in exec_query
    cursor.execute(formatted_sql_string, param_tuple)
  File "/usr/remote/anaconda-3.6/lib/python3.6/site-packages/MySQLdb/cursors.py", line 250, in execute
    self.errorhandler(self, exc, value)
  File "/usr/remote/anaconda-3.6/lib/python3.6/site-packages/MySQLdb/connections.py", line 50, in defaulterrorhandler
    raise errorvalue
  File "/usr/remote/anaconda-3.6/lib/python3.6/site-packages/MySQLdb/cursors.py", line 247, in execute
    res = self._query(query)
  File "/usr/remote/anaconda-3.6/lib/python3.6/site-packages/MySQLdb/cursors.py", line 411, in _query
    rowcount = self._do_query(q)
  File "/usr/remote/anaconda-3.6/lib/python3.6/site-packages/MySQLdb/cursors.py", line 374, in _do_query
    db.query(q)
  File "/usr/remote/anaconda-3.6/lib/python3.6/site-packages/MySQLdb/connections.py", line 292, in query
    _mysql.connection.query(self, query)
_mysql_exceptions.ProgrammingError: (1064, "You have an error in your SQL syntax; check the manual that corresponds to your MariaDB server version for the right syntax to use near ')' at line 1")
```

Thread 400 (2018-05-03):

Corrupted sensor data

DTV96Calibre, 2018-05-03:
The Packet library doesn't use a parity bit for the serial connection it opens. Change this so that it uses a parity bit [Arduino Reference](https://www.arduino.cc/reference/en/language/functions/communication/serial/begin/)

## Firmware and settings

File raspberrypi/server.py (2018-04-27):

from arduinoToPi import *
from piToDb import *
import os

def main():
	print("Starting pi server...")
	print("Current directory: " + str(os.getcwd()))
	
	master_queue = Queue()
	
	# Note: we need a comma after the queue to indicate that we want a tuple,
	# rather than just an expression with parentheses around it.
	arduino_thread = Thread(target=arduino_main, args=(master_queue,))
	db_thread = Thread(target=database_main, args=(master_queue,))
	
	arduino_thread.start()
	db_thread.start()
	arduino_thread.join()
	db_thread.join()

if __name__ == "__main__":
	main()

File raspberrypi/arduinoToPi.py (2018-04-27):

try:
	import serial
except:
	print("""
	To install pyserial:
	
	sudo apt-get install python3-pip
	sudo pip3 install pyserial

	This program will now hang until force-quit, to ensure you see this message.
	""")
	while True:
		pass

import signal
import datetime
import fcntl
import re
import traceback
import subprocess
import os
import json
from threading import Thread
from queue import Queue
import sys
import array

# global keep-alive
mainThreadAlive = False

# The database_main uses this to reserve an arduino's I/O.
# If it's None, then there is no reservation.
# 
# If it's (name, None), then the arduino with id_string() == name should be reserved, but
# the worker thread may not have finished.
# 
# If it's (name, usb_port), then the arduino with id_string() == name is now reserved, and
# usb_port is the associated port.
reserved_arduino = None

# Array of ArduinoWorkers. This is global because it's used by the database_main thread to
# figure out what arduinos are currently plugged in.
workers = []

# Ensure that we're running python3.
if sys.version_info[0] < 3:
	raise Exception("Must run the pi server using python3. Check that you used the 'python3' command.")

# Use a signal handler to catch Ctrl+C instead of a KeyboardInterrupt exception.
def ctrl_c_handler(signal, frame):
	print("FORCE Shutting down...")
	os._exit(0)

signal.signal(signal.SIGINT, ctrl_c_handler)

# One copy of this thread is spawned to look for new USB devices.
# master_queue is a thread-safe queue of SensorReading objects.
def arduino_main(master_queue):
	assert(isinstance(master_queue, Queue))

	global mainThreadAlive
	#reset_all_usb_ports()

	# Array of ArduinoWorkers
	global workers

	global reserved_arduino

	# Used for the no-workers message.
	last_no_worker_warning = datetime.datetime.now()
	no_worker_warning_interval = datetime.timedelta(seconds=5)

	while True:
		try:
			mainThreadAlive = True

			# Check that all the arduino threads are ok.
			dead_workers = []
			for worker in workers:
				if not worker.getThread().is_alive():
					# TODO: Error handling.
					print("Joining worker: %s", worker.getId())
					worker.getThread().join()
					dead_workers.append(worker)
			for worker in dead_workers:
				workers.remove(worker)

			# Check if any new devices have been plugged in.
			open_ports = []
			for port in get_all_usb_ports():
				if port.hasDevice():
					conflict = False
					for worker in workers:
						if port.getId() == worker.getId():
							conflict = True
							break
					# If this port is reserved, skip it.
					# Note: If there is no worker thread, and the Port field of the reserved_arduino
					# tuple is None, then we still need to spawn a thread, so that it can give its
					# port to the code_download_main thread.
					if reserved_arduino and port.getId() == reserved_arduino[0] and reserved_arduino[1]:
						conflict = True

					if not conflict:
						# No conflicts
						open_ports.append(port)
				

			# Check if any of the open ports are arduinos.
			# TODO: Currently, this assumes all tty's returned by get_all_usb_ports() are
			# arduinos.
			arduino_ports = open_ports
			#arduino_ports = []
			#for port in open_ports:
			#	# TODO: Make this less hacky.
			#	if "Arduino" in port.getName():
			#			arduino_ports.append(port)

			# Make new threads.
			for port in arduino_ports:
				print("Connecting to port: %s", port.getId())
				arduino_id = port.getId()
				thread = Thread(target=arduino_thread, args=(master_queue, port))
				worker = ArduinoWorker(arduino_id, thread)
				workers.append(worker)
				thread.start()
				print("Worker started: %s", worker.getId())
			
			# Check if there are no connected devices.
			if len(workers) == 0 and datetime.datetime.now() - last_no_worker_warning > no_worker_warning_interval:
				print("Warning: no devices detected.")
				last_no_worker_warning = datetime.datetime.now()
			
		except (KeyboardInterrupt, SystemExit):
			print("KeyboardInterrupt or SystemExit; cleaning up...");
			mainThreadAlive = False
			for worker in workers:
				print("Waiting for worker %s..." % worker.getId())
				worker.getThread().join()
			workers = []
			print("done")
			return
		except Exception as e:
			print(e)

def get_open_ports():
	open_ports = []
	for port in get_all_usb_ports():
		if port.hasDevice():
			open_ports.append(port)
	return open_ports

# This thread is spawned for each connected arduino.
def arduino_thread(master_queue, port):
	assert(isinstance(master_queue, Queue))
	assert(isinstance(port, UsbPort))

	# We need to discard the first line. HOWEVER, the very first thing we do MUST
	# be to check if the port is reserved. Only arduino_threads can reserve ports;
	# if a port is reserved in the middle of a read, then it will raise an exception,
	# kill this thread, and then arduino_main thread will spin up a new copy.
	has_read_first_line = False

	global mainThreadAlive
	global reserved_arduino
	try:
	
		while (mainThreadAlive):
			# Check if someone is trying to reserve this port.
			if reserved_arduino:
				print("Thread: ReservedArduino[0] = " + str(reserved_arduino[0]) + ", id=" + port.getId())
				if reserved_arduino[0] == port.getId():
					# Give our port object to the code_download_main thread.
					reserved_arduino = (reserved_arduino[0], port)

					# Exit.
					print("Thread %s: Reserving." % port.getId())
					return

			# Check if we've gotten rid of the first line of junk.
			if not has_read_first_line:
				has_read_first_line = True
				
				# Read one line of input, and then discard it. Either it's the start of the program,
				# and the buffer cuts off the first few chars the arduino sends; OR another thread
				# before this one threw an exception partway through reading, and the next reading
				# is junk.
				try:
					read_packet(port)
				except:
					pass

			# Get sensor data from the arduino.
			json = read_packet(port)

			# Get the current time as a UNIX timestamp.
			# TODO: Get the timestamp before parsing the json?
			time = datetime.datetime.now()

			# Send it to the queue.
			queue_entry = SensorReading(time, json, port.getId())
			master_queue.put(queue_entry)
		print("Thread %s: mainThreadAlive is %s; closing" % (port.getId(), str(mainThreadAlive)))
		return
	except:
		# TODO: Error handling.
		# Currently, if there's an error, the thread ends.
		print(traceback.format_exc())
		return


# Read one packet from the arduino, parse it, and return it.
# TODO: Document why we need hardware_id! (see: read_line())
def read_packet(arduino):
	assert(isinstance(arduino, UsbPort))

	text = read_json(arduino)
	packet = parse_packet(text)
	return packet
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

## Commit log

2017-10-27 Made landing page a Google Map with point on Energy Hill
2017-10-28 Added notes about the arduino-pi interface.
    closes #85, closes #79.
2017-10-28 More notes about arduino stuff.
2017-10-29 Basic ugly landing page has smaller map and some placeholder text
2017-11-08 Changed config file path to work with Bucknell servers
2017-11-08 Just kidding. Needs to be relative to the Flower/WebServer dir
2017-11-13 sensor alerts generalized
2017-11-15 Prepared python script to run for long periods of time, for any arduino model. Not tested yet, at all.
2017-11-15 Added support for more arduino boards; updated thermristor code calibrated for currently used thermristor. None of this is tested.
2017-11-16 ping.py works, calibration is broken.
    [test_thermistor.ino]
2017-11-28 Thermistor code is calibrated and working
    The RawADC value was being measured relative to 5v, while we were
    assuming it was measured relative to 3.3v. To calibrate the
    temperatures, Ben found the datasheet for the thermistor, and it
    turns out to be an NTCLP100E3103H thermistor. Using that, and
    switching from the Steinhart-Hart equation to the Beta equation,
    the temperature readings are now correct, +/- 2 degrees F or so.
    [test_thermistor.ino]
2017-11-28 Made the arduino report data in the right format
    Also finally renamed ping.py and removed the comments at the top
    about not using python in the final product.
2017-12-04 Revert "Merge pull request #151 from BucknellSustainability/124-js-linter"
    This reverts commit 8b05ddf5696398c134ad2b725f0b1048822883a2, reversing
    changes made to 81206bbfc1b6fc4b370275a10c1d1fa69555aa23.
2018-01-20 Renamed arduino and pi folders to match the all lowercase naming of web
2018-01-22 Revert "merged robust_thermistor"
    This reverts commit 8fe7aee0a7e5d144c3f33d011ed3fcebcb265160.
    [test_thermistor.ino]
2018-01-22 Revert "Revert "merged robust_thermistor""
    This reverts commit 99a88790b40fe1cf34e057357d8b3f9cba06da3f.
    [test_thermistor.ino]
2018-02-01 Added json communication library for arduino
2018-02-06 Switching over to flask
2018-02-07 Validation set up for user updated sensor information
2018-02-12 Restructured packet library into arduino library structure
2018-02-12 Added airtemp/humidity arduino code example
2018-02-15 arduinoToPi.py debugged.
2018-02-19 arduinoToPi works.
2018-02-21 N SENSORS WORKS!
2018-02-23 Fixed wrong unix timestamp
    [arduinoToPi.py, piToDb.py]
2018-02-25 Added get-all-sensors endpoint
2018-03-04 Fixed a bunch of compilation errors
    [Packet.cpp]
2018-03-20 unclaimed device query works w/ prod
2018-03-25 Fixed not reporting user defined project name
    [Packet.cpp]
2018-03-25 Added Temperature/Humidity sensor example
2018-03-25 Added barometric sensor example
2018-04-04 Enabled and fixed the png attachment creation
2018-04-09 Code from the pi to the arduino is working
    I also added typechecking everywhere to catch bugs faster.
    I scrapped my old threading model for downloading files, and went
    with a simpler one where only one file can be downloaded at a time.
    Currently, the file that is sent to the arduino is hardcoded. The pi
    can look at the codeupload table, figure out if a connected arduino
    needs code uploaded, etc. However, I'm having a lot of trouble getting
    python to download webpages, which is how it will download the hex
    file for the arduino.
    [arduinoToPi.py, piToArduino.py, piToDb.py]
2018-04-10 Added admin user approval endpoint, protected admin status from update/insert, and fixed visualize
2018-04-16 Added example code for soil moisture sensor
2018-04-19 Made endpoint for cool dyanamic landing page markers
2018-04-24 Changed landing page heading
2018-04-26 Cleanup raspberrypi directory, README, etc
2018-04-27 Fix read buffer
    Fixed the previous hack where it would just blindly read 100 chars
    and look for exactly one data point. It now reads char by char.
    I also fixed some indentation errors caused by my previous PR.
    [arduinoToPi.py, piToDb.py, server.py]
2018-05-03 Added updated CAD files for Data Harvester
    [backplane.DXF, backplane.SLDPRT, backplane_wConstruction.DXF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]
2018-05-03 Added updated bill of materials
    [BOM.csv]
